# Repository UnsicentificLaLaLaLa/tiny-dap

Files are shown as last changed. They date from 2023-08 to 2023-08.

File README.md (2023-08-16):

# tiny-dap

[TOC]

## 介绍

基于 TinyUSB 和 CMSIS-5 实现的 CMSIS-DAP，支持 SWD 调试接口和串口通信。

选择 TinyUSB 作为协议栈的原因是 TinyUSB 开源免费，且适配多家 MCU，具有良好的通用性。

基于 CMSIS-5 实现 CMSIS-DAP 可以降低移植 DapLink 的难度，降低实现门槛。

## 文件结构

- hardware

    - v1.x

        tiny-dap 的硬件实现，使用 KiCad 7.0 设计，已生成生产文件和原理图。

        - production

            使用 KiCad 嘉立创提供的插件生成的生产文件。

- software

    tiny-dap 的软件实现，基于 MM32F0162D4Q。

## 适配芯片

目前计划采用 MM32F0162D4Q 作为 tiny-dap 的 MCU，后续也将计划在更多 QFN32 芯片上实现 tiny-dap，如果有精力的话。

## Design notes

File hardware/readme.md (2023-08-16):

- v1.0
    - 初版 tiny-dap 硬件，基于 MM32F0162D4Q 设计
- v1.1
    - 基于 v1.0，移除了复位电路，移除了一个 LED，移除了微控制器电源的电容，移除了 USB 信号线上串联的 22R 电阻，减小了 PCB 尺寸

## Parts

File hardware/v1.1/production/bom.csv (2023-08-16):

Designator | Footprint | Quantity | Value | LCSC Part #
C1, C2 | 0603 | 2 | 1uF
D1, D2 | 0603 | 2 | LED
J1 | USB_C_Receptacle_HRO_TYPE-C-31-M-12 | 1 | USB_C_Receptacle_USB2.0
J2 | PinHeader_2x04_P2.54mm_Horizonal_Edge | 1 | Conn_02x04_Odd_Even
R1, R2 | 0603 | 2 | 5K1
R3, R4 | 0603 | 2 | 4K7
TP1, TP2 | TestPoint_Pad_D1.0mm | 2 | SWCLK
TP3 | TestPoint_Pad_D1.0mm | 1 | GND
U1 | QFN-32-1EP_5x5mm_P0.5mm_EP3.6x3.6mm | 1 | MCU
U2 | SOT-23 | 1 | XC6206PxxxMR

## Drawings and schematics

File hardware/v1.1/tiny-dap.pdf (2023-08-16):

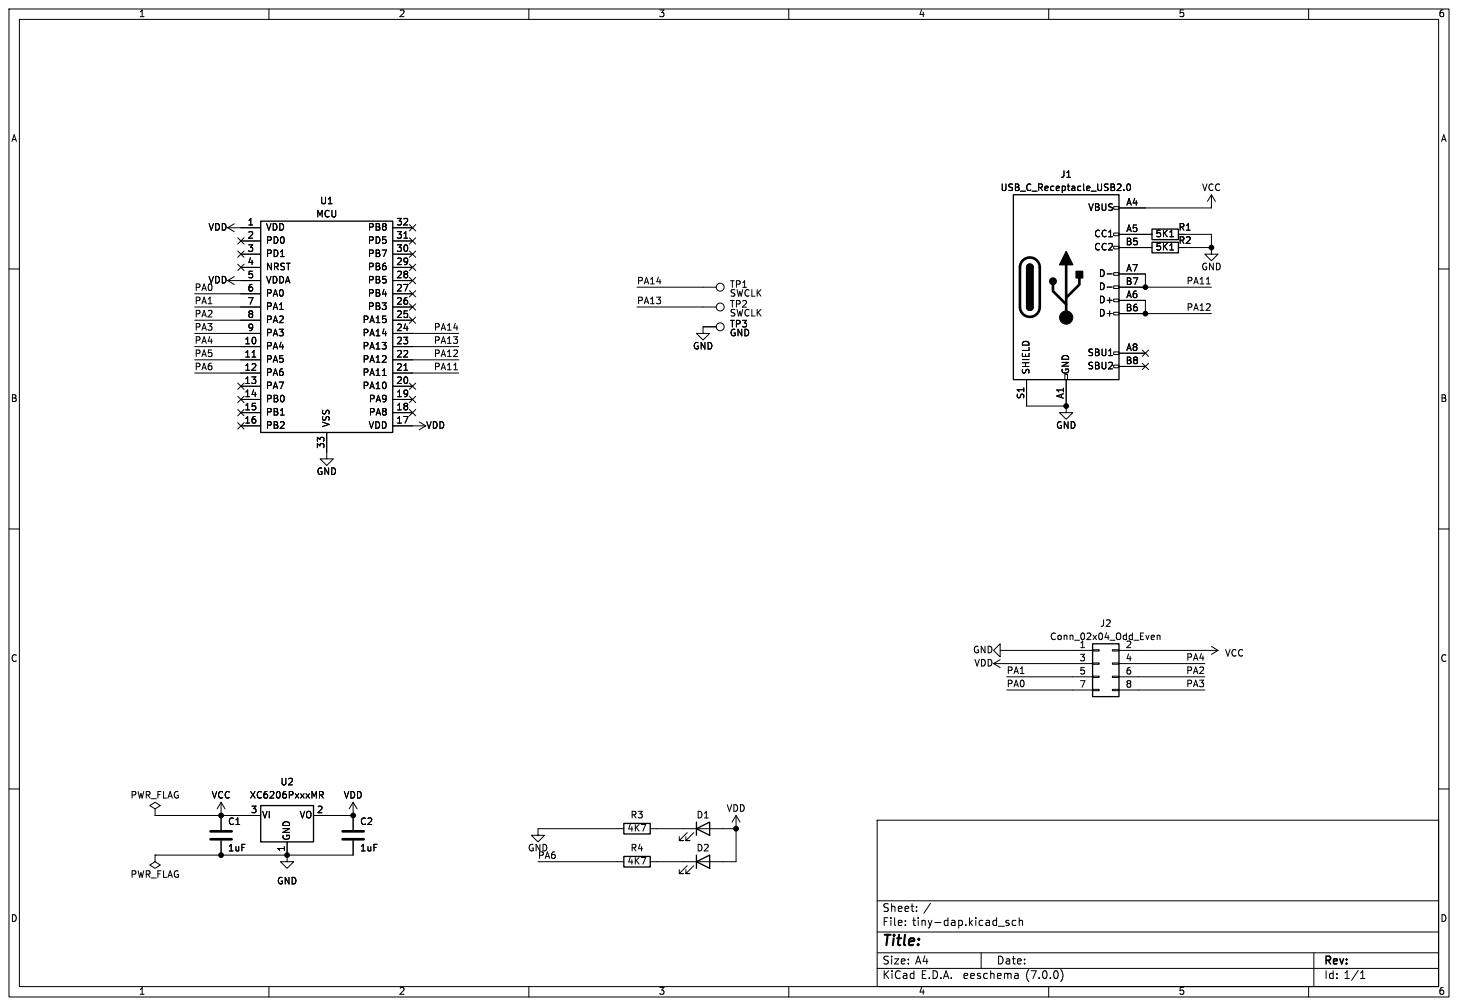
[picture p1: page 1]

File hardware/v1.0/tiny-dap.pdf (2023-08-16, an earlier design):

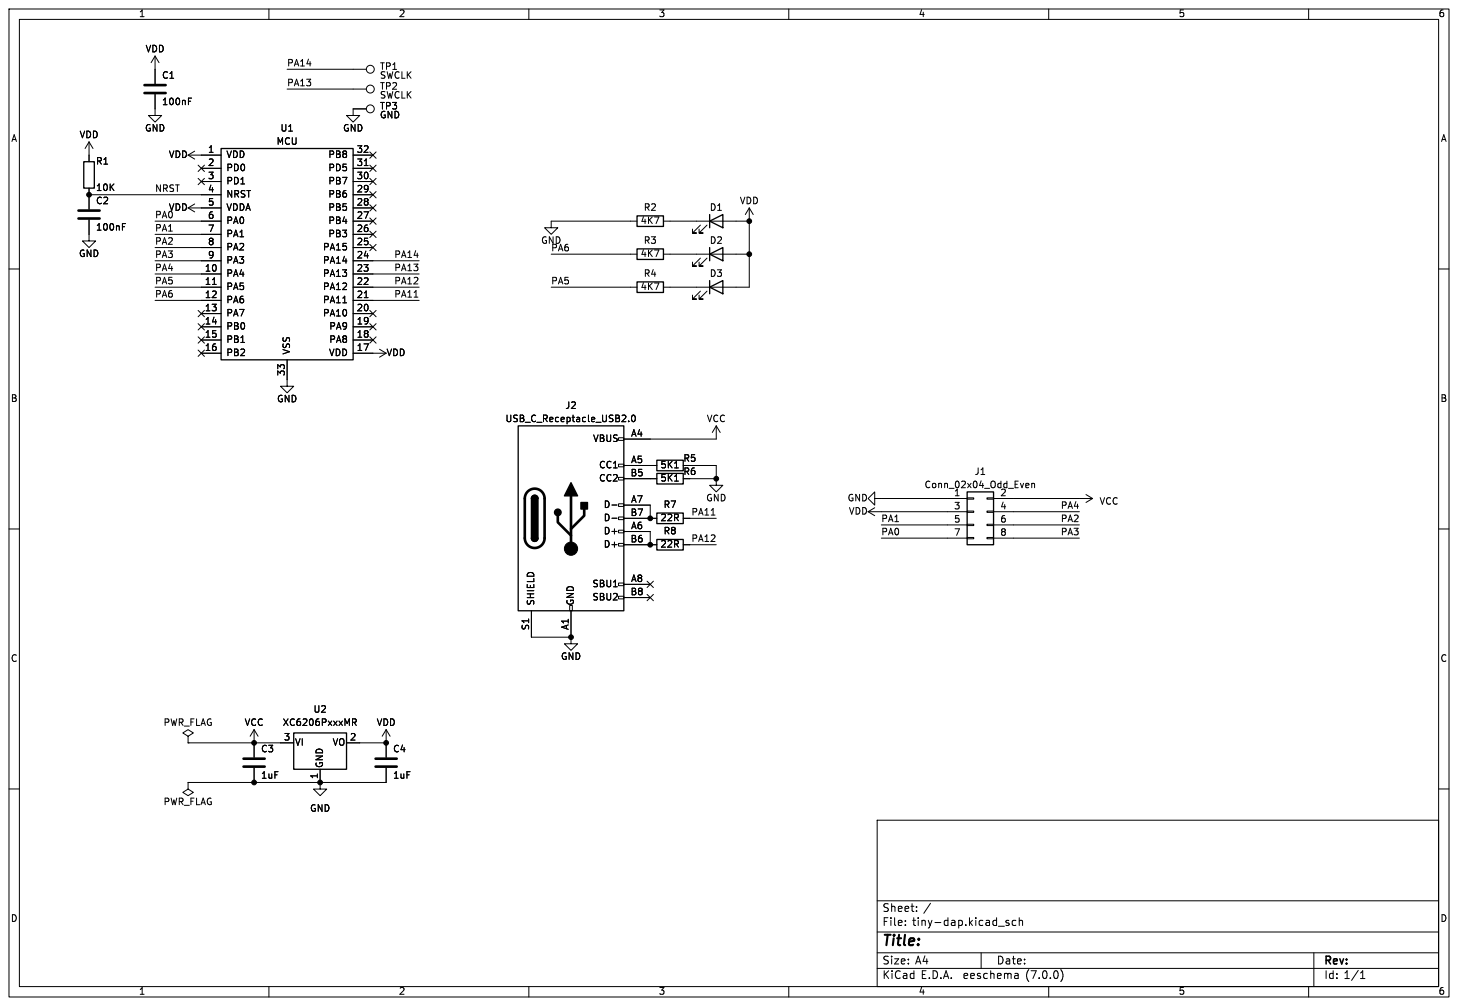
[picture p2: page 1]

Id: 1/1 Title: File: tiny-dap.kicad_sch Sheet: /

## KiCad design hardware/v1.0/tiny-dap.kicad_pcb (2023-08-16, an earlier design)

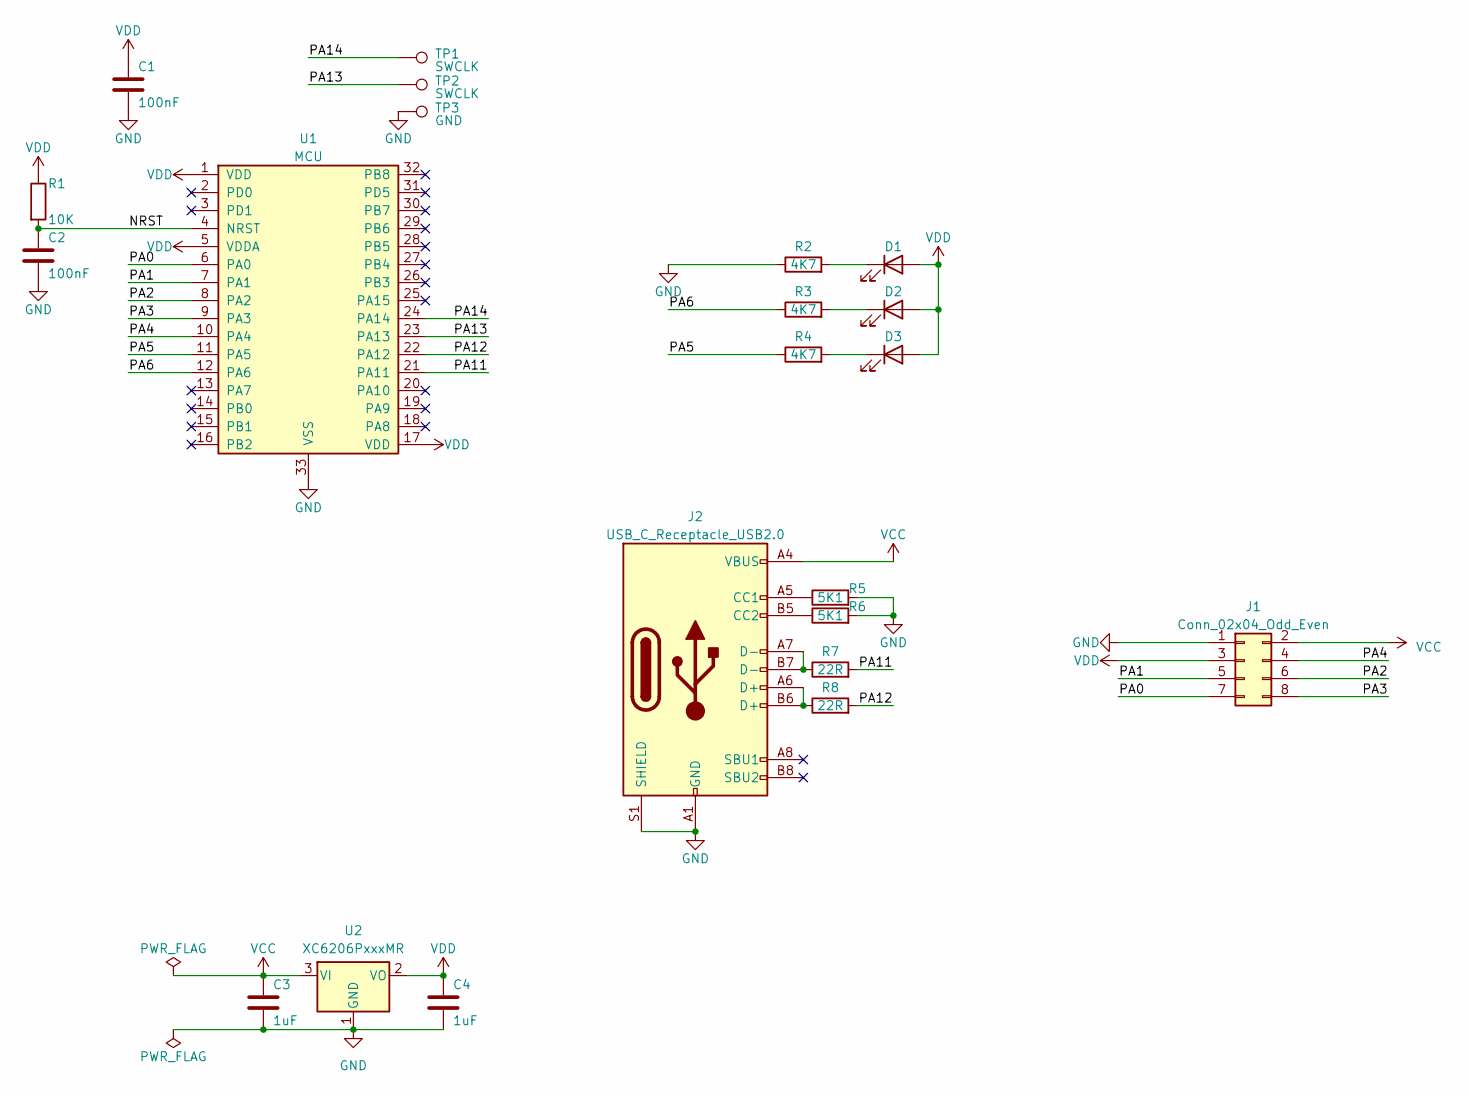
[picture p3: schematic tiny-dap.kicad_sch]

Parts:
C1, C2: 100nF; C_0603_1608Metric_Pad1.08x0.95mm_HandSolder
C3, C4: 1uF; C_0603_1608Metric_Pad1.08x0.95mm_HandSolder
D1, D2, D3: LED; LED_0603_1608Metric_Pad1.05x0.95mm_HandSolder
J1: Conn_02x04_Odd_Even; PinHeader_2x04_P2.54mm_Horizonal_Edge
J2: USB_C_Receptacle_USB2.0; USB_C_Receptacle_HRO_TYPE-C-31-M-12
R1: 10K; R_0603_1608Metric_Pad0.98x0.95mm_HandSolder
R2, R3, R4: 4K7; R_0603_1608Metric_Pad0.98x0.95mm_HandSolder
R5, R6: 5K1; R_0603_1608Metric_Pad0.98x0.95mm_HandSolder
R7, R8: 22R; R_0603_1608Metric_Pad0.98x0.95mm_HandSolder
TP1, TP2: SWCLK; TestPoint_Pad_D1.0mm
TP3: GND; TestPoint_Pad_D1.0mm
U1: MCU; QFN-32-1EP_5x5mm_P0.5mm_EP3.6x3.6mm
U2: XC6206PxxxMR; SOT-23

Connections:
/NRST: C2.1, R1.2, U1.4 (NRST)
/PA0: J1.7, U1.6 (PA0)
/PA1: J1.5, U1.7 (PA1)
/PA2: J1.6, U1.8 (PA2)
/PA3: J1.8, U1.9 (PA3)
/PA4: J1.4, U1.10 (PA4)
/PA5: R4.1, U1.11 (PA5)
/PA6: R3.1, U1.12 (PA6)
/PA11: R7.2, U1.21 (PA11)
/PA12: R8.2, U1.22 (PA12)
/PA13: TP2.1, U1.23 (PA13)
/PA14: TP1.1, U1.24 (PA14)
GND: C1.2, C2.2, C3.2, C4.2, J1.1, J2.A1 (GND), J2.A12 (GND), J2.B1 (GND), J2.B12 (GND), J2.S1 (SHIELD), R2.1, R5.2, R6.2, TP3.1, U1.33 (VSS), U2.1 (GND)
unnamed: D1.1 (K), R2.2
unnamed: D2.1 (K), R3.2
unnamed: D3.1 (K), R4.2
unnamed: J2.A5 (CC1), R5.1
unnamed: J2.B5 (CC2), R6.1
unnamed: J2.A6 (D+), J2.B6 (D+), R8.1
unnamed: J2.A7 (D-), J2.B7 (D-), R7.1
VCC: C3.1, J1.2, J2.A4 (VBUS), J2.A9 (VBUS), J2.B4 (VBUS), J2.B9 (VBUS), U2.3 (VI)
VDD: C1.1, C4.1, D1.2 (A), D2.2 (A), D3.2 (A), J1.3, R1.1, U1.1 (VDD), U1.5 (VDDA), U1.17 (VDD), U2.2 (VO)

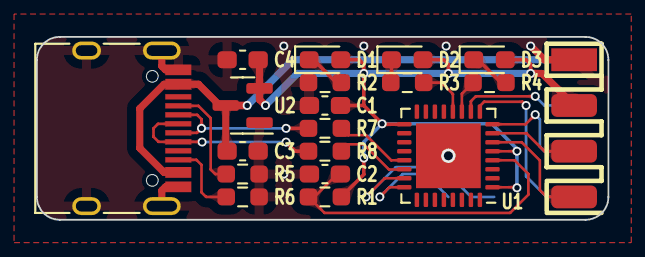
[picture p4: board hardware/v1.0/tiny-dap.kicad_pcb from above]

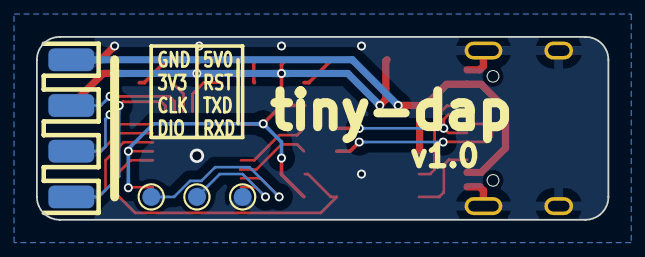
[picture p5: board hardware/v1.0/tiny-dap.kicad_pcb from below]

Board: 2 copper layers, 31.8 x 10.2 mm, 22 parts (3 on the bottom side), 22 nets.

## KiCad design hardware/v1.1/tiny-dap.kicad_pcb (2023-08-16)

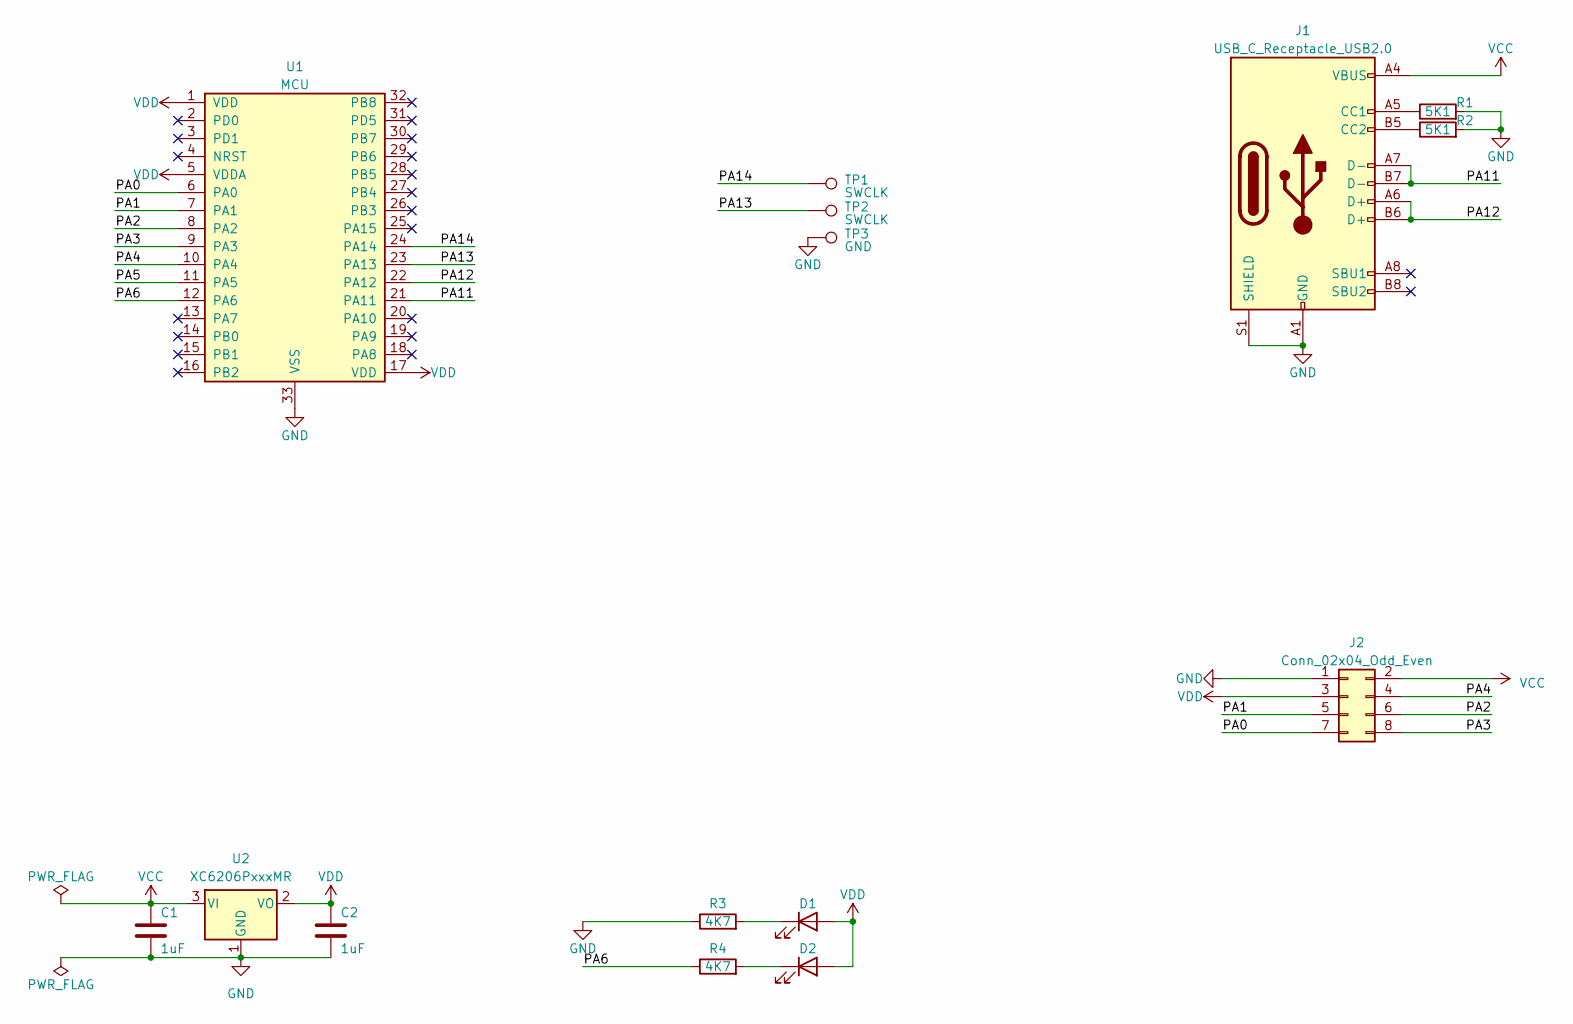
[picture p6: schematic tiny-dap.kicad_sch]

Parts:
C1, C2: 1uF; C_0603_1608Metric_Pad1.08x0.95mm_HandSolder
D1, D2: LED; LED_0603_1608Metric_Pad1.05x0.95mm_HandSolder
J1: USB_C_Receptacle_USB2.0; USB_C_Receptacle_HRO_TYPE-C-31-M-12
J2: Conn_02x04_Odd_Even; PinHeader_2x04_P2.54mm_Horizonal_Edge
R1, R2: 5K1; R_0603_1608Metric_Pad0.98x0.95mm_HandSolder
R3, R4: 4K7; R_0603_1608Metric_Pad0.98x0.95mm_HandSolder
TP1, TP2: SWCLK; TestPoint_Pad_D1.0mm
TP3: GND; TestPoint_Pad_D1.0mm
U1: MCU; QFN-32-1EP_5x5mm_P0.5mm_EP3.6x3.6mm
U2: XC6206PxxxMR; SOT-23

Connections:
/PA0: J2.7, U1.6 (PA0)
/PA1: J2.5, U1.7 (PA1)
/PA2: J2.6, U1.8 (PA2)
/PA3: J2.8, U1.9 (PA3)
/PA4: J2.4, U1.10 (PA4)
/PA5: U1.11 (PA5)
/PA6: R4.1, U1.12 (PA6)
/PA11: J1.A7 (D-), J1.B7 (D-), U1.21 (PA11)
/PA12: J1.A6 (D+), J1.B6 (D+), U1.22 (PA12)
/PA13: TP2.1, U1.23 (PA13)
/PA14: TP1.1, U1.24 (PA14)
GND: C1.2, C2.2, J1.A1 (GND), J1.A12 (GND), J1.B1 (GND), J1.B12 (GND), J1.S1 (SHIELD), J2.1, R1.2, R2.2, R3.1, TP3.1, U1.33 (VSS), U2.1 (GND)
unnamed: D1.1 (K), R3.2
unnamed: D2.1 (K), R4.2
unnamed: J1.A5 (CC1), R1.1
unnamed: J1.B5 (CC2), R2.1
VCC: C1.1, J1.A4 (VBUS), J1.A9 (VBUS), J1.B4 (VBUS), J1.B9 (VBUS), J2.2, U2.3 (VI)
VDD: C2.1, D1.2 (A), D2.2 (A), J2.3, U1.1 (VDD), U1.5 (VDDA), U1.17 (VDD), U2.2 (VO)

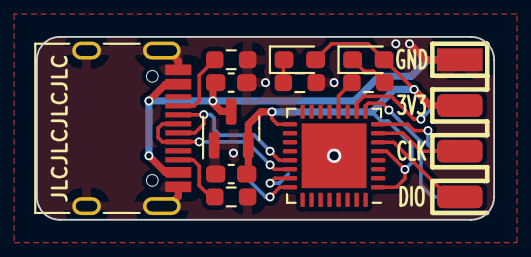
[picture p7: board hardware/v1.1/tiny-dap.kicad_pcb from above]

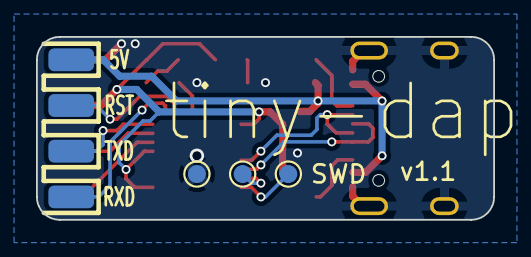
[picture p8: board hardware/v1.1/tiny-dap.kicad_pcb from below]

Board: 2 copper layers, 25.4 x 10.2 mm, 15 parts (3 on the bottom side), 17 nets.

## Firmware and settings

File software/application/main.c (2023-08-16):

/*
 * MIT License
 *
 * Copyright (c) 2023 UnsicentificLaLaLaLa
 *
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
 */

#include "platform.h"
#include "tusb.h"
#include "DAP.h"

/* cdc task. */
void cdc_task(void);

int main(void)
{
    platform_init(); /* init board. */
    tusb_init(); /* init tinyusb. */
    DAP_Setup(); /* init dap. */

    while (1)
    {
        tud_task();
        cdc_task();
    }
}

/* hid callback. */

/* Invoked when received GET_REPORT control request
 * Application must fill buffer report's content and return its length.
 * Return zero will cause the stack to STALL request
 */
uint16_t tud_hid_get_report_cb(uint8_t itf, uint8_t report_id, hid_report_type_t report_type, uint8_t* buffer, uint16_t reqlen)
{
    (void) itf;
    (void) report_id;
    (void) report_type;
    (void) buffer;
    (void) reqlen;

    return 0;
}

/* Invoked when received SET_REPORT control request or
 * received data on OUT endpoint ( Report ID = 0, Type = 0 )
 */
uint8_t hid_tx_data_buf[CFG_TUD_HID_EP_BUFSIZE];
void tud_hid_set_report_cb(uint8_t itf, uint8_t report_id, hid_report_type_t report_type, uint8_t const* buffer, uint16_t bufsize)
{
    (void) report_type;

    uint32_t response_size = TU_MIN(CFG_TUD_HID_EP_BUFSIZE, bufsize);
    DAP_ExecuteCommand(buffer, hid_tx_data_buf);
    tud_hid_n_report(itf, report_id, hid_tx_data_buf, response_size);
}

/* cdc task & callback. */

void cdc_task(void)
{
    if ( tud_cdc_n_connected(0))
    {
        if (uart_rx_available() && tud_cdc_n_write_available(0) > 0)
        {
            uint8_t rx_buf[64];
            uint32_t rx_cnt = uart_rx(rx_buf, tud_cdc_n_write_available(0));
            tud_cdc_n_write(0, rx_buf, rx_cnt);
            tud_cdc_n_write_flush(0);
        }
        if (uart_tx_idle() && tud_cdc_n_available(0) > 0)
        {
            char tx_buf[128] = "012345678\r\n";
            uint32_t tx_cnt = tud_cdc_n_read(0, tx_buf, sizeof(tx_buf));
            uart_tx((uint8_t*)tx_buf, tx_cnt);
        }
    }
}

/* Invoked when line coding is change via SET_LINE_CODING
 */
void tud_cdc_line_coding_cb(uint8_t itf, cdc_line_coding_t const* p_line_coding)
{
    uart_init(p_line_coding);
}

/* main.c - end */

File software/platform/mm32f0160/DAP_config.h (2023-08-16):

/*
 * Copyright (c) 2013-2021 ARM Limited. All rights reserved.
 *
 * SPDX-License-Identifier: Apache-2.0
 *
 * Licensed under the Apache License, Version 2.0 (the License); you may
 * not use this file except in compliance with the License.
 * You may obtain a copy of the License at
 *
 * www.apache.org/licenses/LICENSE-2.0
 *
 * Unless required by applicable law or agreed to in writing, software
 * distributed under the License is distributed on an AS IS BASIS, WITHOUT
 * WARRANTIES OR CONDITIONS OF ANY KIND, either express or implied.
 * See the License for the specific language governing permissions and
 * limitations under the License.
 *
 * ----------------------------------------------------------------------
 *
 * $Date:        16. June 2021
 * $Revision:    V2.1.0
 *
 * Project:      CMSIS-DAP Configuration
 * Title:        DAP_config.h CMSIS-DAP Configuration File (Template)
 *
 *---------------------------------------------------------------------------*/

#ifndef __DAP_CONFIG_H__
#define __DAP_CONFIG_H__


//**************************************************************************************************
/**
\defgroup DAP_Config_Debug_gr CMSIS-DAP Debug Unit Information
\ingroup DAP_ConfigIO_gr
@{
Provides definitions about the hardware and configuration of the Debug Unit.

This information includes:
 - Definition of Cortex-M processor parameters used in CMSIS-DAP Debug Unit.
 - Debug Unit Identification strings (Vendor, Product, Serial Number).
 - Debug Unit communication packet size.
 - Debug Access Port supported modes and settings (JTAG/SWD and SWO).
 - Optional information about a connected Target Device (for Evaluation Boards).
*/

#include "hal_rcc.h"
#include "hal_gpio.h"
#include "stdio.h"

/// Processor Clock of the Cortex-M MCU used in the Debug Unit.
/// This value is used to calculate the SWD/JTAG clock speed.
#define CPU_CLOCK               96000000  ///< Specifies the CPU Clock in Hz.

/// Number of processor cycles for I/O Port write operations.
/// This value is used to calculate the SWD/JTAG clock speed that is generated with I/O
/// Port write operations in the Debug Unit by a Cortex-M MCU. Most Cortex-M processors
/// require 2 processor cycles for a I/O Port Write operation.  If the Debug Unit uses
/// a Cortex-M0+ processor with high-speed peripheral I/O only 1 processor cycle might be
/// required.
#define IO_PORT_WRITE_CYCLES    2U              ///< I/O Cycles: 2=default, 1=Cortex-M0+ fast I/0.

/// Indicate that Serial Wire Debug (SWD) communication mode is available at the Debug Access Port.
/// This information is returned by the command \ref DAP_Info as part of <b>Capabilities</b>.
#define DAP_SWD                 1               ///< SWD Mode:  1 = available, 0 = not available.

/// Indicate that JTAG communication mode is available at the Debug Port.
/// This information is returned by the command \ref DAP_Info as part of <b>Capabilities</b>.
#define DAP_JTAG                0               ///< JTAG Mode: 1 = available, 0 = not available.

/// Configure maximum number of JTAG devices on the scan chain connected to the Debug Access Port.
/// This setting impacts the RAM requirements of the Debug Unit. Valid range is 1 .. 255.
#define DAP_JTAG_DEV_CNT        0U              ///< Maximum number of JTAG devices on scan chain.

/// Default communication mode on the Debug Access Port.
/// Used for the command \ref DAP_Connect when Port Default mode is selected.
#define DAP_DEFAULT_PORT        1U              ///< Default JTAG/SWJ Port Mode: 1 = SWD, 2 = JTAG.

/// Default communication speed on the Debug Access Port for SWD and JTAG mode.
/// Used to initialize the default SWD/JTAG clock frequency.
/// The command \ref DAP_SWJ_Clock can be used to overwrite this default setting.
#define DAP_DEFAULT_SWJ_CLOCK   1000000U        ///< Default SWD/JTAG clock frequency in Hz.

/// Maximum Package Size for Command and Response data.
/// This configuration settings is used to optimize the communication performance with the
/// debugger and depends on the USB peripheral. Typical vales are 64 for Full-speed USB HID or WinUSB,
/// 1024 for High-speed USB HID and 512 for High-speed USB WinUSB.
#define DAP_PACKET_SIZE         64U             ///< Specifies Packet Size in bytes.

/// Maximum Package Buffers for Command and Response data.
/// This configuration settings is used to optimize the communication performance with the
/// debugger and depends on the USB peripheral. For devices with limited RAM or USB buffer the
/// setting can be reduced (valid range is 1 .. 255).
#define DAP_PACKET_COUNT        1U              ///< Specifies number of packets buffered.

/// Indicate that UART Serial Wire Output (SWO) trace is available.
/// This information is returned by the command \ref DAP_Info as part of <b>Capabilities</b>.
#define SWO_UART                0               ///< SWO UART:  1 = available, 0 = not available.
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

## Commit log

2023-08-16 add hardware v1.0.
    - add tiny-dap 1.0 pcb design file.
    [bom.csv, designators.csv, positions.csv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]
2023-08-16 add hardware v1.1.
    - add tiny-dap v1.1 pcb file.
    [bom.csv, designators.csv, positions.csv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]
2023-08-16 hardware bugfix.
    - modify usb cc pin res val 22R -> 5K1.
    [bom.csv, tiny-dap.kicad_pcb, tiny-dap.kicad_sch]
